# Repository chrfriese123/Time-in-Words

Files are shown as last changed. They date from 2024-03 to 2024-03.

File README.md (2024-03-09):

# Time expressed by words

## Introduction

The concept of presenting the current time by individual words is not new and demonstrated quite often e.g. on Youtube. Out of curiousity this private project was started without considering too much input from other sources. The goal was to prepare one working demonstrator. 

## Basic setup

The principle setup consist of a front plate with cut-outs for the indiviual letters, an illumnination electronic behind each letter and a control circuit to control the individual LEDs.

### Front plate
For the front plate a suitbale svg template was created with Inkscape. All together over 100 letters are required. The file was then transferred with laser cutting into a steel plate. To have a stable, non bending plate, 2mm steel was choosen.

*Lessons learned: this is (too) heavy, thinner would be acceptable.*

### Electronics
To generate a uniform illumniation behind each letter, two RGBW LEDs (SK6812) were considered for each letter. This sums up to a total of over 200 LEDs that needed to be driven and powered in a row. They are mounted on individual small PCBs as this approach seemed more cost efficient than having a huge PCB behind the entire front plate. 

*Lessons learned: lot of soldering between the PCBs needed.*

### Control units
An ESP32 based setup was choosen to drive the LEDs. A simple look-up table is used to translate the current time into a definition of which LED to switch on/off. The time is retrieved by NTP which turned out to be not reliable enough. Adding a RTC to the setup solved the challenge. The power is supplied by a USB-C connection providing sufficient power. To control the behavior (color & intensity) of the clock, a simple async server was setup on the ESP. 

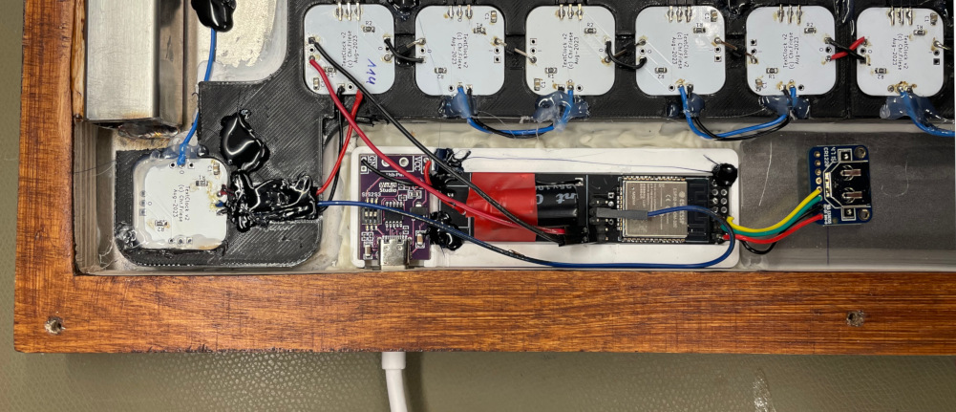
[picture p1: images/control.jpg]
Controls


*Lessons learned: do not rely on Wifi, use RTC as backup.*

### Assembly
For aligning the PCBs to the letters a 3D printed frame was used. This frame also prevents cross-talk of the illumnation between the different elements. To hide the LEDs from the frontside, the frame was partially filled with epoxy. White pigments were added to the epoxy. Unfortunately this lead to a color shift of the LEDs and less defined appearance. To hide all the installation, hot glue and flying wires a wooden backplate was attached to the setup.

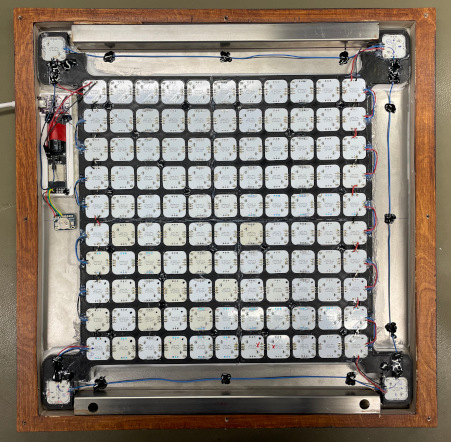
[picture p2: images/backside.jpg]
Backside


*Lessons learned: "white" epoxy screws up color fidelity.*

## Conclusion
The demonstrator works and looks nice. I used and combined a couple of new technologies (for myself) and learned a lot for future projects. After considering all the effort (material, hours), it seems more reasonable, why a commercial product is expensive.

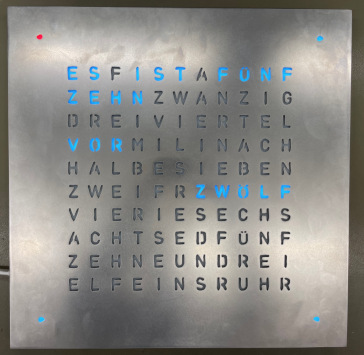
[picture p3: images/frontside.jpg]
Frontside


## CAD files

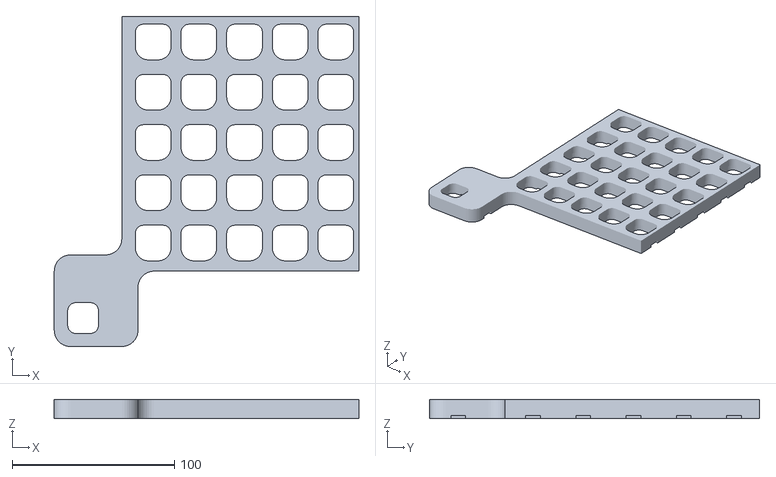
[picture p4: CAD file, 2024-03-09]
cad/TextClock_v3_Spacer_lr.STL
187.8 x 203.6 x 12.0

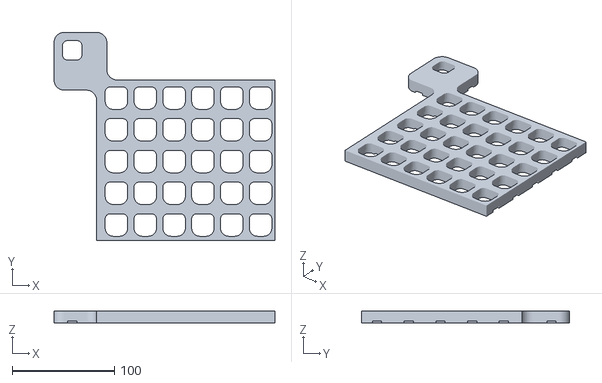
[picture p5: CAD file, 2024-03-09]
cad/TextClock_v3_Spacer_ur.STL
216.0 x 203.6 x 12.0

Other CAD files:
cad/TextClock_v3_Spacer_ll.STL
cad/TextClock_v3_Spacer_ul.STL

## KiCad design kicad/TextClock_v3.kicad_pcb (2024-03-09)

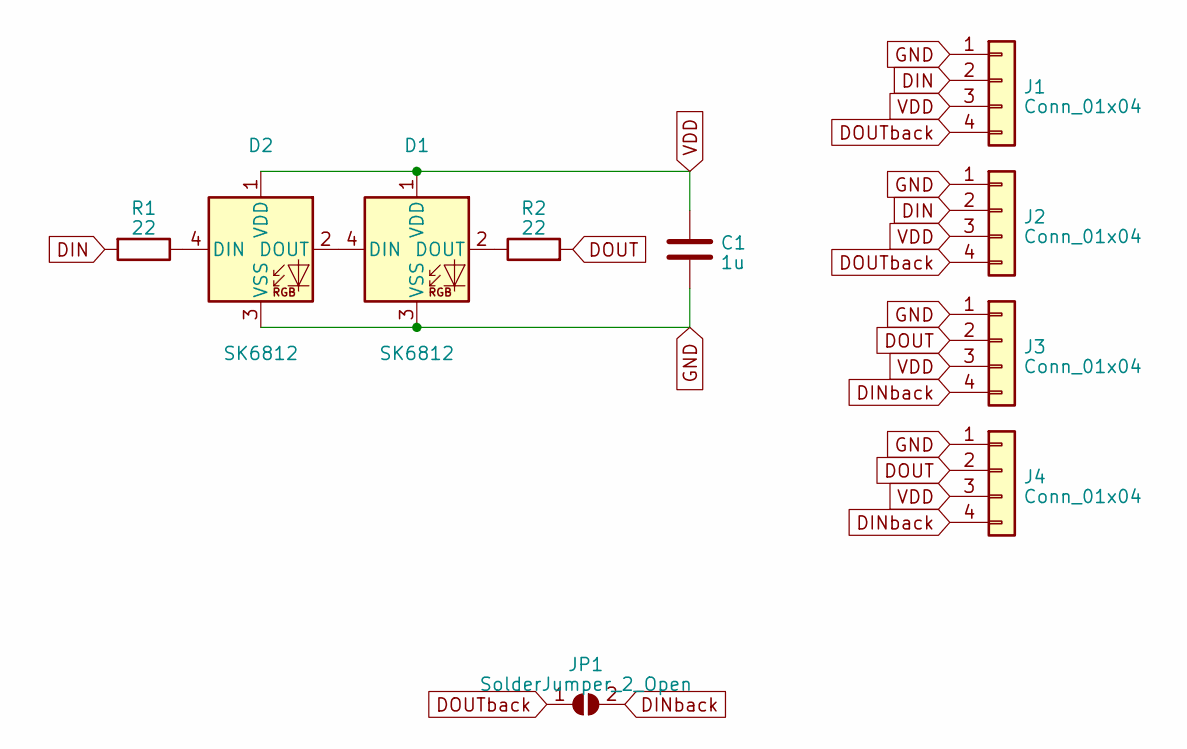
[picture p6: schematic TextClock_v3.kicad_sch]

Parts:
C1: 1u; C_0805_2012Metric_Pad1.18x1.45mm_HandSolder
D1, D2: SK6812; LED_WS2812B_PLCC4_5.0x5.0mm_P3.2mm
J1, J2, J3, J4: Conn_01x04; PinHeader_1x04_P2.54mm_Vertical
JP1: SolderJumper_2_Open; SolderJumper-2_P1.3mm_Open_RoundedPad1.0x1.5mm
R1, R2: 22; R_0805_2012Metric_Pad1.20x1.40mm_HandSolder

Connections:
DIN: J1.2, J2.2, R1.2
DINback: J3.4, J4.4, JP1.2 (B)
DOUT: J3.2, J4.2, R2.2
DOUTback: J1.4, J2.4, JP1.1 (A)
GND: C1.2, D1.3 (VSS), D2.3 (VSS), J1.1, J2.1, J3.1, J4.1
unnamed: D1.4 (DIN), D2.2 (DOUT)
unnamed: D1.2 (DOUT), R2.1
unnamed: D2.4 (DIN), R1.1
VDD: C1.1, D1.1 (VDD), D2.1 (VDD), J1.3, J2.3, J3.3, J4.3

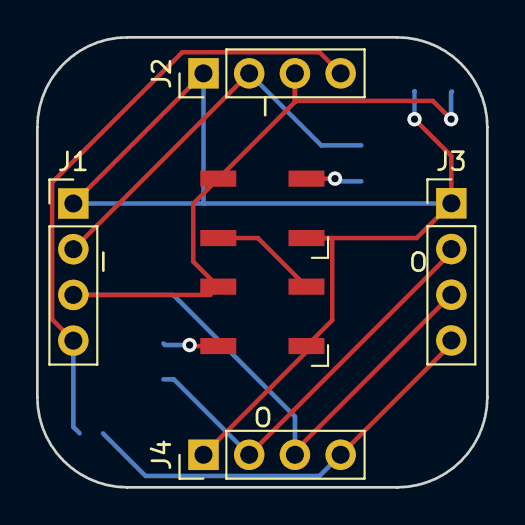
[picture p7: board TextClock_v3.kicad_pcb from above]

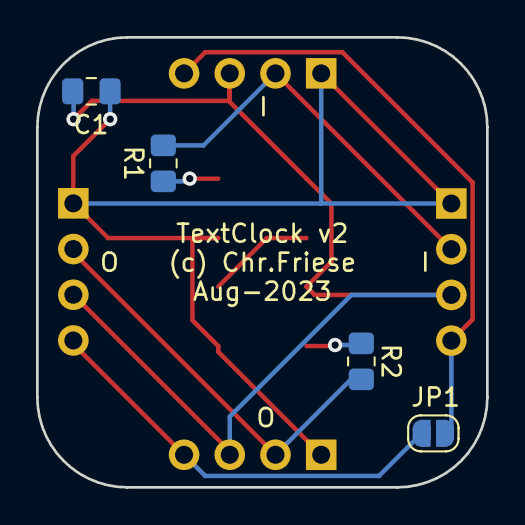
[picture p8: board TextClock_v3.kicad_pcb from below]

Board: 2 copper layers, 25.0 x 25.0 mm, 10 parts (4 on the bottom side), 9 nets.

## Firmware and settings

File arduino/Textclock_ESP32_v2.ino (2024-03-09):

//-------------------------------------------------
//
//  Testuhr v2
//
//-------------------------------------------------

// Funktionen:  - Wifi Verbindung
//              - Webseite bereitstellen für Konfiguration (Farbe & Helligkeit / Tag & Nacht)
//              - NTP Netzwerkzeit abrufen
//              - Uhrzeit anzeigen
// V2:
// - Add RTC module
// - Shift Neopixel display to task loop (independent of Wifi AP)
// - Listen to MDNS entry
//
// RGBW         
// Rot      max 100..120
// Grün     max 100..120    
// Blau     max 100..120    
// Weiss        

#include "00_config.h"

void setup() {
  setCpuFrequencyMhz(80);

  //Setup watchdog system
  counterData = millis();
  //wdtSetup();

  // Setup serial output
  serial_setup();
  wdtReset();

  // Setup Neopixel output
  neopixel_setup();
  wdtReset();

  // Setup file system handling
  fs_setup();
  wdtReset();  

  // Setup RTC read function
  rtc_setup();
  wdtReset();

   //Offload neopixel display to task (run independent on AP)
  xTaskCreatePinnedToCore(neopixel_loop,"Neopixel_Loop",10000,NULL,0,&NeopixelLoopTask,1);
  wdtReset();

  // Setup Wifi connection, potentially with Access Point
  wifi_setup();
  wdtReset();

  wdtSetup();

  Serial.println(F("Setup complete!\t"));
  Serial.println(F("\n#####################################\n"));
  Serial.println(F("Start TextClock\n"));
}

void loop() {
  
  //if (millis() - counterData > CYC_UPDATE) { 
    //wifi_check();
    //espDelay(10000);
    //neopixel_set();
//    counterData = millis();   
//  }
  delay (200);
  
  wdtReset();
}

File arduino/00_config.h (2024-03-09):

#ifndef __CONFIG_H_
#define __CONFIG_H_

/***********************************************************************
Key libraries needed for any other file
***********************************************************************/

#include <Wire.h>
#include "SPI.h"
#include "I2Cbus.h"          // I2Cbus library

#include <time.h>            // time() ctime()
time_t nowWIFI;                  // this is the epoch
tm * tmWIFI;                     // the structure tm holds time information in a more convient way

uint16_t CYC_UPDATE = 2000;
uint32_t counterData;        //replace timer function

/***********************************************************************
Watchdog setup & task handler (only ESP32)
***********************************************************************/

TaskHandle_t NeopixelLoopTask;

#include <esp_task_wdt.h>
#include <esp_err.h>

#define WDT_TIMEOUT               32 //Seconds

void wdtSetup() {
  ESP_ERROR_CHECK(esp_task_wdt_init(WDT_TIMEOUT, true));
  ESP_ERROR_CHECK(esp_task_wdt_add(NULL));                 //add current thread to WDT watch  
}

void wdtReset() {
  vTaskDelay(0);
  esp_task_wdt_reset();
}
  
//! Long time delay, it is recommended to use shallow sleep, which can effectively reduce the current consumption
void espDelay(int ms)
{
    esp_sleep_enable_timer_wakeup(ms * 1000);
    esp_sleep_pd_config(ESP_PD_DOMAIN_RTC_PERIPH, ESP_PD_OPTION_ON);
    esp_light_sleep_start();
}

#define ESP_getChipId()           ((uint32_t)ESP.getEfuseMac())

/***********************************************************************
01.1 Filesystem
***********************************************************************/
#include "FS.h"
  
// Valid setup for esp32 core from release 2.09 onwards
#include <LittleFS.h>
FS* filesystem =                  &LittleFS;
#define FileFS                    LittleFS
#define FS_Name                   "LittleFS"

/***********************************************************************
01.2 JSON config file
***********************************************************************/

#include <ArduinoJson.h>

//StaticJsonDocument<1024>              systemDoc;
String configJSON = "";
DynamicJsonDocument                   configDoc(2000);
//extern void     validate_json();
extern bool parseJSON();
  
char dummyJSON[] = "{\"General\":{\
\"tagStunde\":8,\
\"tagMinute\":0,\
\"tagBunt\":1,\
\"tagHell\":50,\
\"tagFarbe\":[10,100,200],\
\"nachtStunde\":21,\
\"nachtMinute\":0,\
\"nachtBunt\":1,\
\"nachtHell\":10,\
\"nachtFarbe\":[200,100,10]\
}\
}";

/***********************************************************************
03 WIFI 
***********************************************************************/

#define _ESPASYNC_WIFIMGR_LOGLEVEL_    2
#define TIME_BETWEEN_CONFIG_PORTAL_LOOP            1L

#include <esp_wifi.h>
#include <WiFi.h>
#include <WiFiClient.h>
#include <WiFiMulti.h>
WiFiMulti wifiMulti;

extern bool activeAP;

// SSID and PW for Config Portal
String  ssid = "TC_" + String(ESP_getChipId(), HEX);

#define NUM_WIFI_CREDENTIALS          2

// SSID and PW for your Access Points
//String Router_SSID[NUM_WIFI_CREDENTIALS] = {"CFVV_IoT","Saumur"};
//String Router_Pass[NUM_WIFI_CREDENTIALS] = {"Hchr2023friS&","Rf1012!2145"};
String Router_SSID[NUM_WIFI_CREDENTIALS] = {" "," "};
String Router_Pass[NUM_WIFI_CREDENTIALS] = {" ", " "};


// You only need to format the filesystem once
#define FORMAT_FILESYSTEM           false

#define MIN_AP_PASSWORD_SIZE        8

#define SSID_MAX_LEN                32
#define PASS_MAX_LEN                64

typedef struct {
  char wifi_ssid[SSID_MAX_LEN];
  char wifi_pw  [PASS_MAX_LEN];
}  WiFi_Credentials;

typedef struct {
  String wifi_ssid;
  String wifi_pw;
}  WiFi_Credentials_String;

#define TZNAME_MAX_LEN                50
#define TIMEZONE_MAX_LEN              50

typedef struct
{
  WiFi_Credentials  WiFi_Creds [NUM_WIFI_CREDENTIALS];
  char TZ_Name[TZNAME_MAX_LEN];     // "Europe/Berlin"
  char TZ[TIMEZONE_MAX_LEN];        // "CET-1CEST,M3.5.0,M10.5.0/3"
  uint16_t checksum;
} WM_Config;

WM_Config                             WM_config;

#define  WIFI_FILENAME                F("/wifi_cred.dat")
#define  CONFIG_FILENAME              F("/configuration.dat")

// Indicates whether ESP has WiFi credentials saved from previous session, or double reset detected
bool initialConfig = false;
#define USE_AVAILABLE_PAGES           false
#define USE_STATIC_IP_CONFIG_IN_CP    false
#define USE_CLOUDFLARE_NTP            false
#define USING_CORS_FEATURE            false
#define USE_DHCP_IP                   true
#define USE_CONFIGURABLE_DNS          false
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
